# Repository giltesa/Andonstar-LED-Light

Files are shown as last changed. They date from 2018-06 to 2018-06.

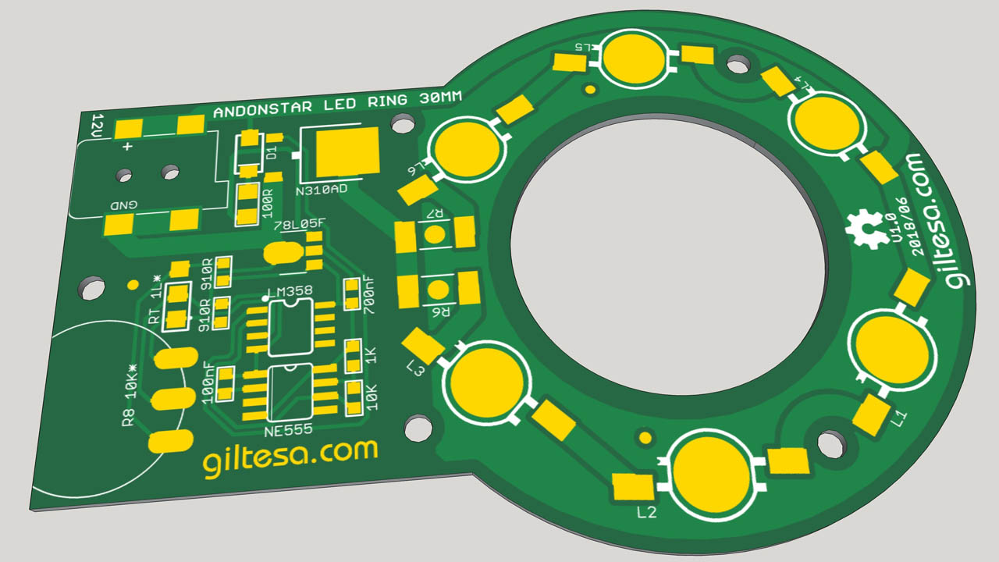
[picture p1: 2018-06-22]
2. Gerbers/Images/2 Top Green.jpg

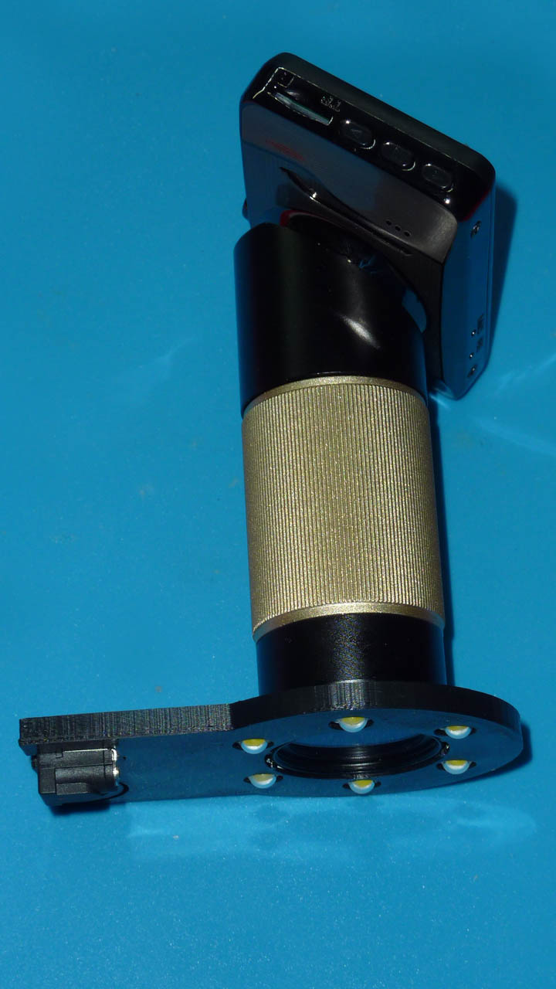
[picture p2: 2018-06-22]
4. Photos/P1170256.JPG

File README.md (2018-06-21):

# Andonstar LED Light

This is an electronic circuit made of aluminum to build a light that attaches to the Andonstar ADSM201 microscope.

Here is more information, but it is in Spanish:
[**Lampara LED para microscopio Andonstar ADSM201**](https://giltesa.com/2018/06/20/lampara-led-para-microscopio-andonstar-adsm201).

Youtube Video:

ANDONSTAR ADSM201 LED RING 6W 12V 30MM (https://www.youtube.com/watch?v=A698UcTd43E)

## License

This project is licensed under the license **Creative Commons** of type: **[Attribution-NonCommercial-ShareAlike 4.0 International (CC BY-NC-SA 4.0) ](https://creativecommons.org/licenses/by-nc-sa/4.0/)**. Check the file [LICENSE.md](LICENSE.md) for more information.

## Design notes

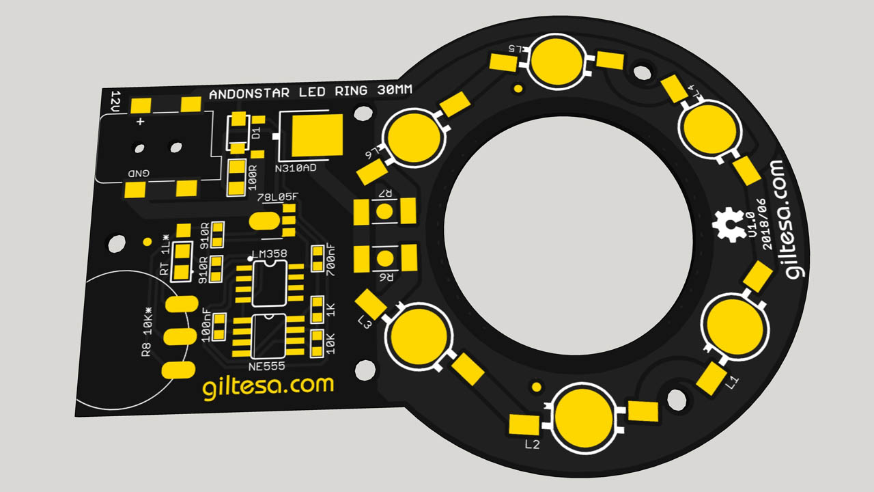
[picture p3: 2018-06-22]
2. Gerbers/Images/1 Top Black.jpg

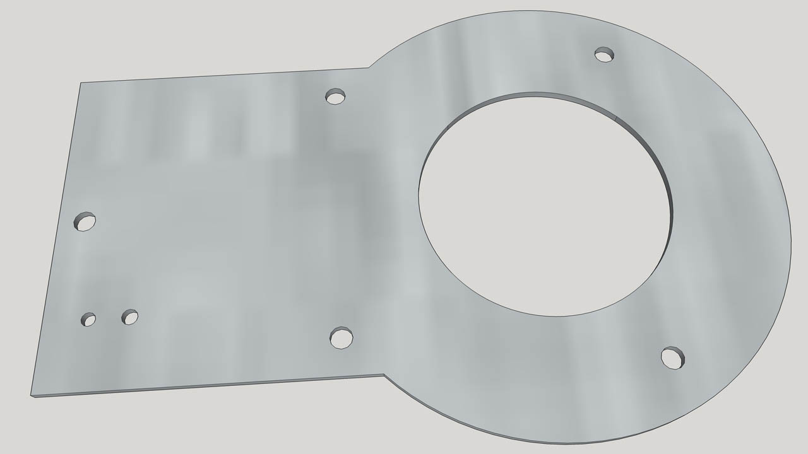
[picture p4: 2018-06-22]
2. Gerbers/Images/3 Bottom.jpg

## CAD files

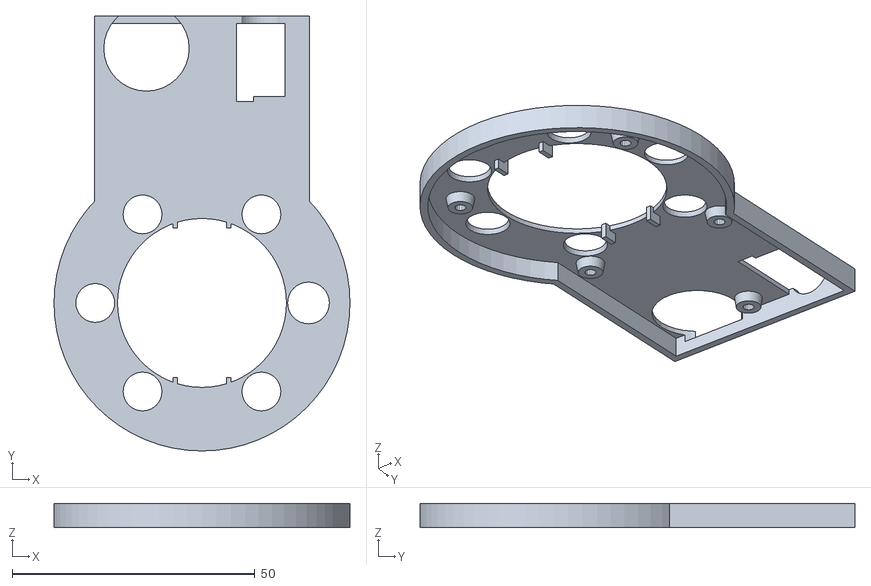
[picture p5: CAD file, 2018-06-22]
3. Box/Andonstar LED Ring.stl
61.0 x 89.6 x 5.00

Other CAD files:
3. Box/Andonstar LED Ring.skp

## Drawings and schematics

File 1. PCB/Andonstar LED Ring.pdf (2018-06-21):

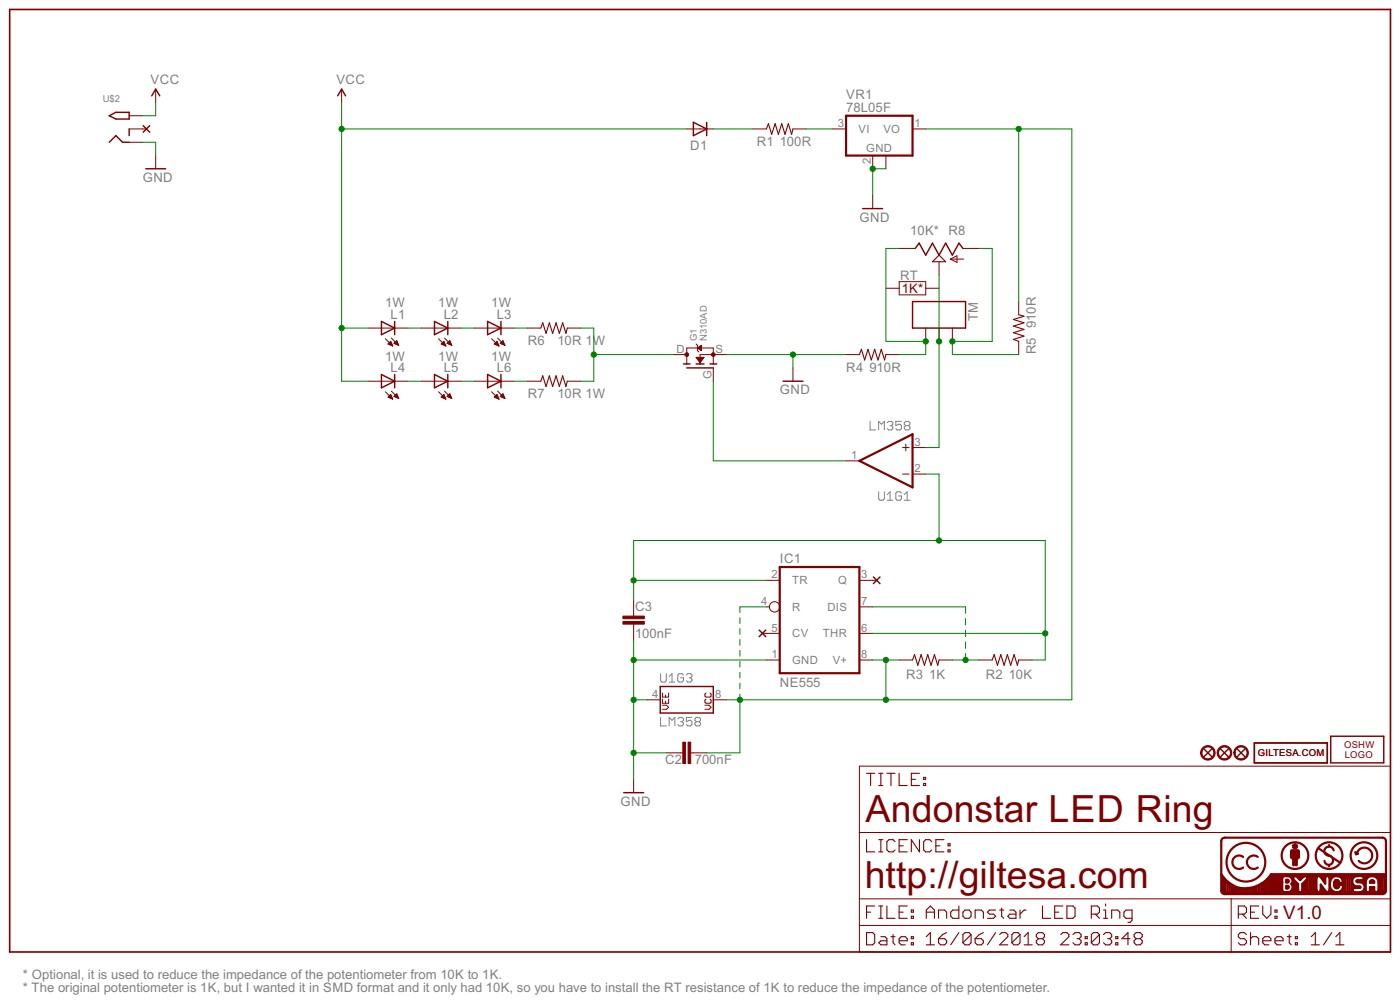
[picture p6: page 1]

* The original potentiometer is 1K, but I wanted it in SMD format and it only had 10K, so you have to install the RT resistance of 1K to reduce the impedance of the potentiometer. * Optional, it is used to reduce the impedance of the potentiometer from 10K to 1K.

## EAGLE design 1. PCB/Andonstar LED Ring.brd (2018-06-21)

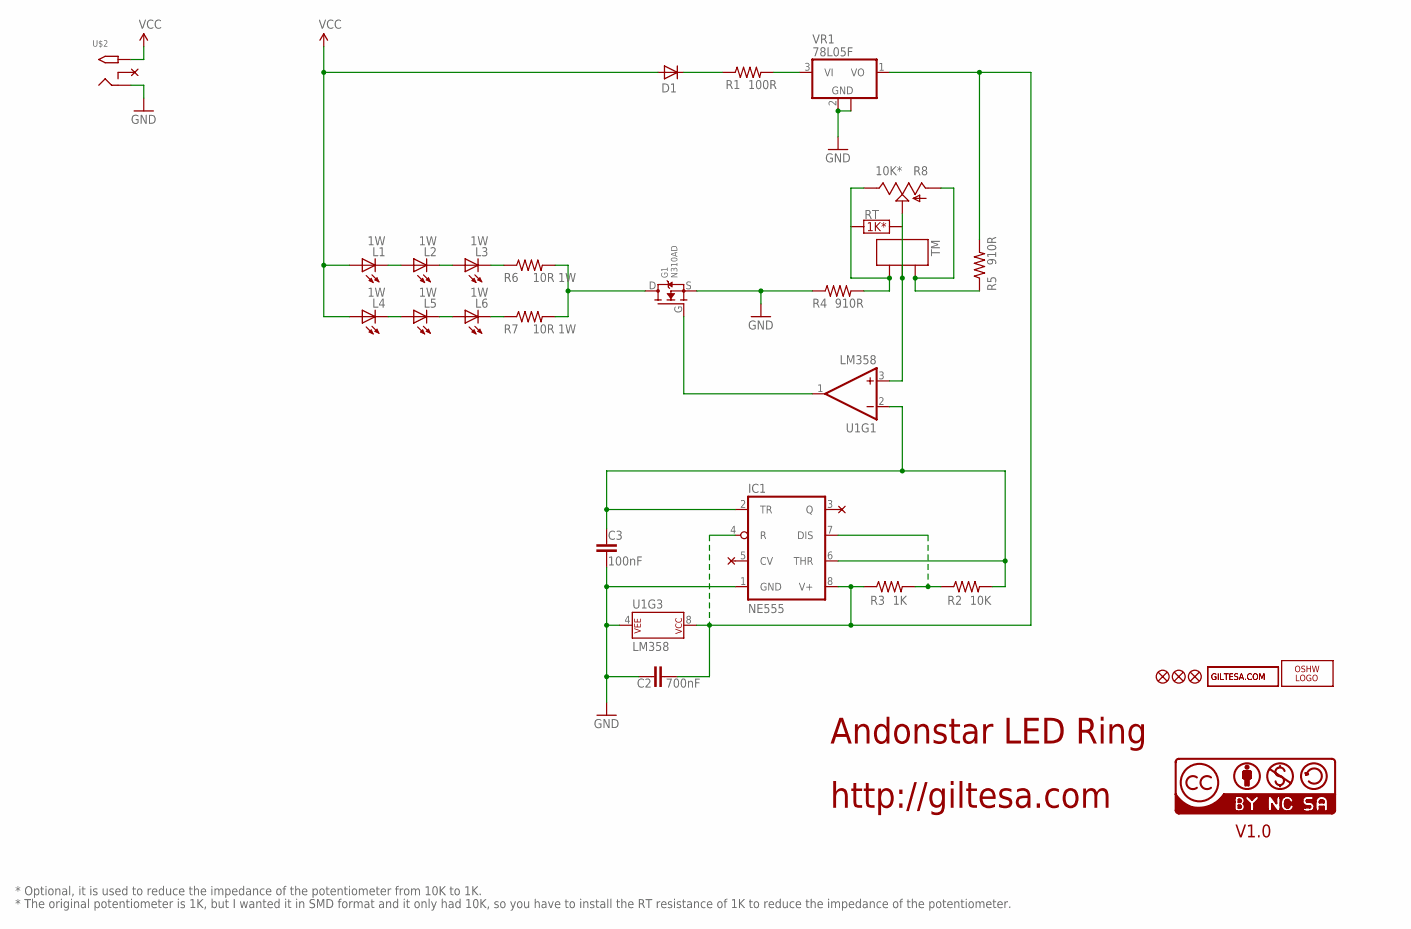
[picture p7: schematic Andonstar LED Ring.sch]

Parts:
C2: 700nF; C0603
C3: 100nF; C0603
D1: DIODE-GF1; GF1
G1: N310AD; TO-252
IC1: NE555; SO08
L1, L2, L3, L4, L5, L6: 1W; LED_Z_POWER
LOGO1: OSHW_LOGO_FILLX0150-NT; OSHW_FILLX150_NOTEXT
R1: 100R; R1206
R2: 10K; R0603
R3: 1K; R0603
R4, R5: 910R; R0603
R6, R7: 10R 1W; R2512
R8: 10K*; TRIMPOT_SMD_16MM
TM: 1X03; 1X03_SMD
U1: LM358; SO08
U$1: GILTESA.COM_MASK
U$2: 2.1MMJACKSMT; DCJACK_2MM_SMT
U$6, U$7, U$14: FIDUCIAL1X2; FIDUCIAL-1X2
U$8: GILTESA.COM_COPPER_STOP
U$20: CC-NC-BCNIX; CC-NC-B_NIX
VR1: 78L05F; SOT89

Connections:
GND: C2.2, C3.1, G1.S, IC1.1 (GND), R4.1, U1.4 (P$V-), U$2.GND (RING), VR1.2 (GND), VR1.2@1 (GND)
unnamed: L5.C, L6.A
unnamed: L4.C, L5.A
unnamed: L2.C, L3.A
unnamed: L1.C, L2.A
unnamed: L3.C, R6.1
unnamed: L6.C, R7.1
unnamed: IC1.7 (DIS), R2.1, R3.2
unnamed: G1.D, R6.2, R7.2
unnamed: C3.2, IC1.2 (TR), IC1.6 (THR), R2.2, U1.2 (-IN)
unnamed: R8.S, TM.2, U1.3 (+IN)
unnamed: R5.1, R8.A, TM.3
unnamed: R4.2, R8.B, TM.1
unnamed: R1.2, VR1.3 (VI)
unnamed: C2.1, IC1.4 (R), IC1.8 (V+), R3.1, R5.2, U1.8 (P$V+), VR1.1 (VO)
unnamed: D1.C, R1.1
unnamed: G1.G, U1.1 (OUT)
VCC: D1.A, L1.A, L4.A, U$2.PWR2 (TIP)

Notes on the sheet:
Andonstar LED Ring
http://giltesa.com
V1.0
1K*
* The original potentiometer is 1K, but I wanted it in SMD format and it only had 10K, so you have to install the RT resistance of 1K to reduce the impedance of the potentiometer.
* Optional, it is used to reduce the impedance of the potentiometer from 10K to 1K.

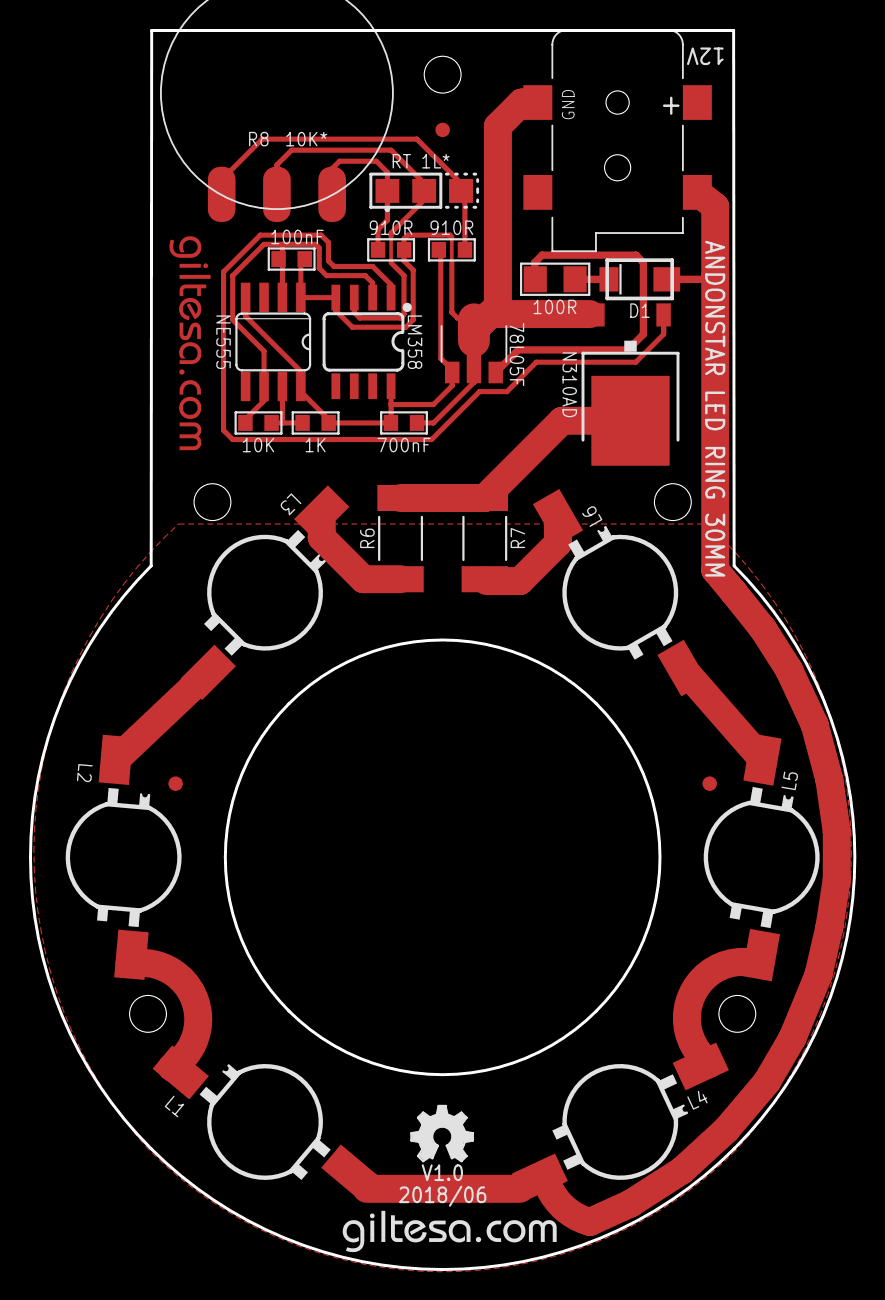
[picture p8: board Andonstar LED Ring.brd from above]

Board: 2 copper layers, 56.9 x 85.4 mm, 30 parts (0 on the bottom side), 18 nets.

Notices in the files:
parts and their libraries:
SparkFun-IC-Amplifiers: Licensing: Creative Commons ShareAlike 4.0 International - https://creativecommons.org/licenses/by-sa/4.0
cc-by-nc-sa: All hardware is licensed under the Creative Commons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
